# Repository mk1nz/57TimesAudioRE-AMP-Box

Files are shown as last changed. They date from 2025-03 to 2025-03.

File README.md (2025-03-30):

# 57TimesAudioRE-AMP-Box
High performance re-amp box using high precission resistors, high quality connectors and Lundahl LL1540 transformer

<br>

Frequency response is around +- 0.2db

<br>
THD 0.071% (about -86.5dbFs at a signal level of -6.6dbFs)<br>
50HZ ripple is at a level of -101.6dbFs.

<br>

# Parts list I used in my build:
  R1, R2 - UXB02070F1202BCU00 Vishay Metal Film Resistors UXB 0207-10 0.1% CU 12K<br>
  R3 - MRS25000C5109FCT00 Vishay Metal Film Resistor - Through Hole MRS25-50 1% CT 51R<br>
  VR1 - P160KNPD-0QC15A10K BI Technologies / TT Electronics Potentiometer, 1/10W 10K Ohms 20% 16mm ROTARY POT<br>
  C1 - FKP3F021003F00KI00 Wima Film Capacitor FKP 3 0.01 uF 250 VDC 5x11x13 PCM 10<br>
  J2 - NRJ6HM-1-PRE Neutrik Phone Connector Jack 1/4" - stereo switched tip and ring (not sleeve), slim-full thread metal-PCBH-cha grd<br>
  J3 - NC3FD-H-B Neutrik XLR Connectors 3C FEMALE PCB BLK/GD<br>
  S1 - DPDT Standard Through Hole PCB Right Angle Push Button Self-lock Switch, similar to 22F02 (Please note that the part number on the schematic is incorrect and differs from that on the Gerber files.)<br>

WARNING: Soldering the pins of the LL1540 should be done as quickly as possible to avoid damaging the transformer. I soldered the transformer at 300 degrees Celsius using high quality flux, applying molten solder to each pin for about 2-3 seconds.

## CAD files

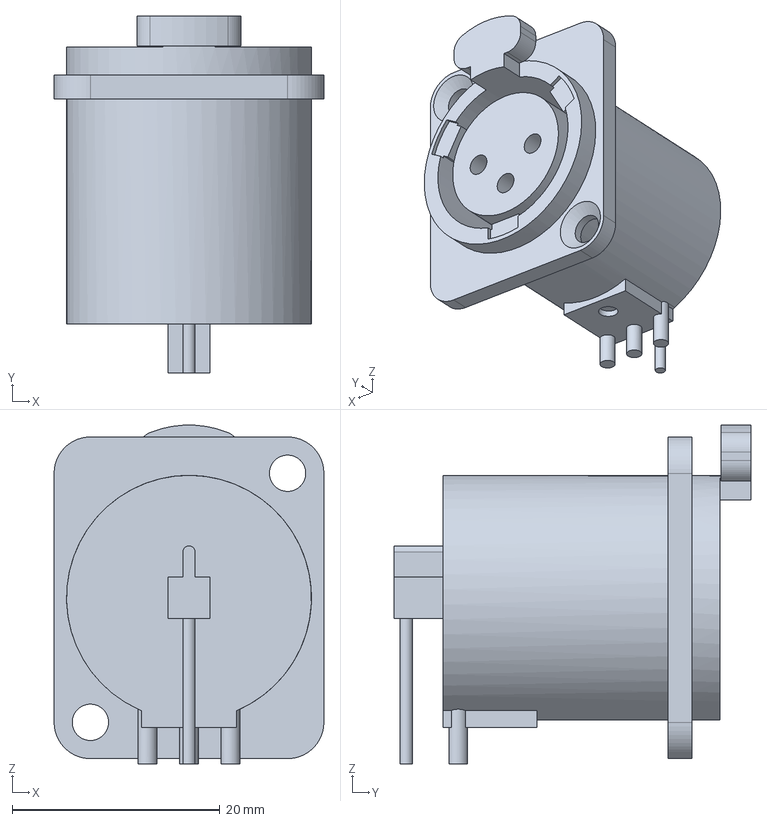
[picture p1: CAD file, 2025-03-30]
57TimesAudioRE-AMP-Kicad/NC3FD-H-B/eec.models/Neutrik_-_NC3FD-H-B.step
26.0 x 34.4 x 32.6 mm

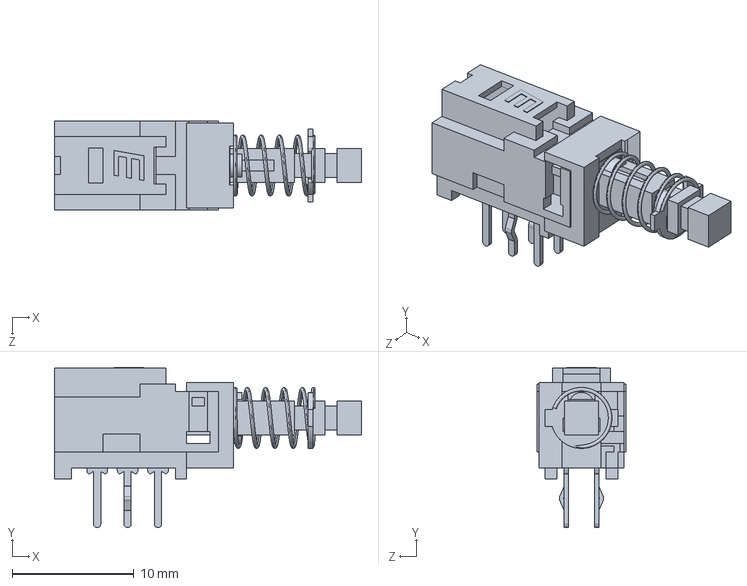
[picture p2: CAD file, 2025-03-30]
57TimesAudioRE-AMP-Kicad/PBH2UEESNPNAGX/PBH2UEESNPNAGX.step
25.2 x 13.2 x 7.30 mm

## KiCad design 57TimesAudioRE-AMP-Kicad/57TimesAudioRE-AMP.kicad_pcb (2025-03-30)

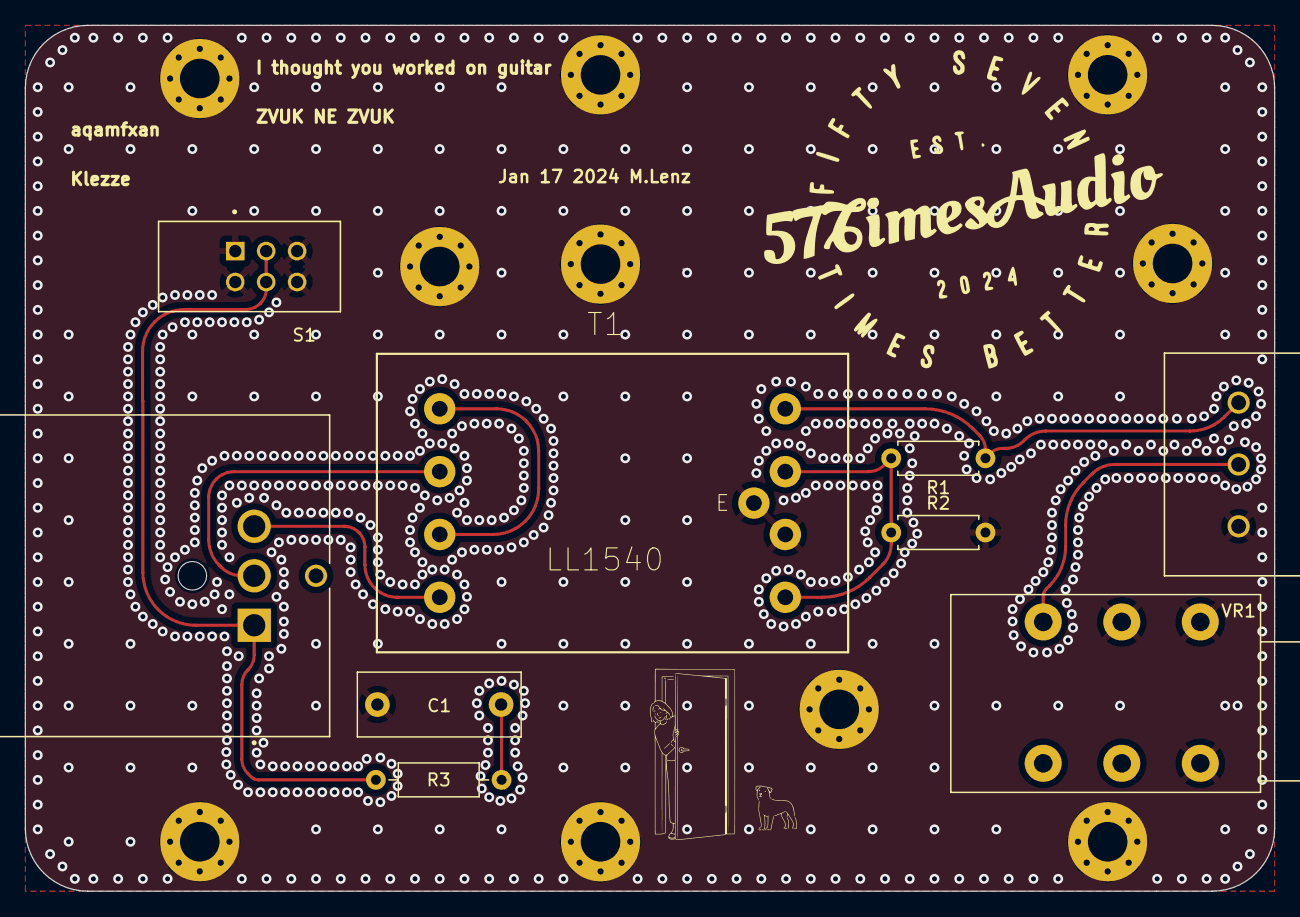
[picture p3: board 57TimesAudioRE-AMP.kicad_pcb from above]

Board: 2 copper layers, 101.0 x 70.0 mm, 9 parts (0 on the bottom side), 9 nets.

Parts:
C1: 10nf; C_Rect_L13.0mm_W5.0mm_P10.00mm_FKS3_FKP3_MKS4
J2: Jack OUT; Jack_6.35mm_Neutrik_NRJ6HM-1-PRE_Horizontal
J3: NC3FAAH-0; NEUTRIK_NC3FD-H-B
R1, R2: 12k; R_Axial_DIN0207_L6.3mm_D2.5mm_P7.62mm_Horizontal
R3: 51; R_Axial_DIN0207_L6.3mm_D2.5mm_P10.16mm_Horizontal
S1: PushButton Right Angle DPDT; SW_PBH2UEESNPNAGX
T1: LL1540; LUNDAHL-LL1540
VR1: P160KN-0QC15A10K; P160

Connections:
GND: C1.2, J2.R, J2.S, R2.2, S1.1, S1.3, S1.4, S1.6, T1.6, T1.E, VR1.1
unnamed: C1.1, R3.2
unnamed: J2.T, VR1.2
unnamed: J3.1, R3.1, S1.2, S1.5
unnamed: J3.2, T1.1
unnamed: J3.3, T1.3
unnamed: R1.1, T1.8, VR1.3
unnamed: R1.2, R2.1, T1.5, T1.7
unnamed: T1.2, T1.4

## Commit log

2025-03-30 Schematic and symbols of the reamp box
    [57TimesAudioRE-AMP-B_Cu.gbl, 57TimesAudioRE-AMP-B_Cu.gbr, 57TimesAudioRE-AMP-B_Mask.gbs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]
2025-03-30 PCB Fabrication files (Gerber)
    [57TimesAudioRE-AMP-B_Cu.gbl, 57TimesAudioRE-AMP-B_Mask.gbs, 57TimesAudioRE-AMP-B_Paste.gbp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]
